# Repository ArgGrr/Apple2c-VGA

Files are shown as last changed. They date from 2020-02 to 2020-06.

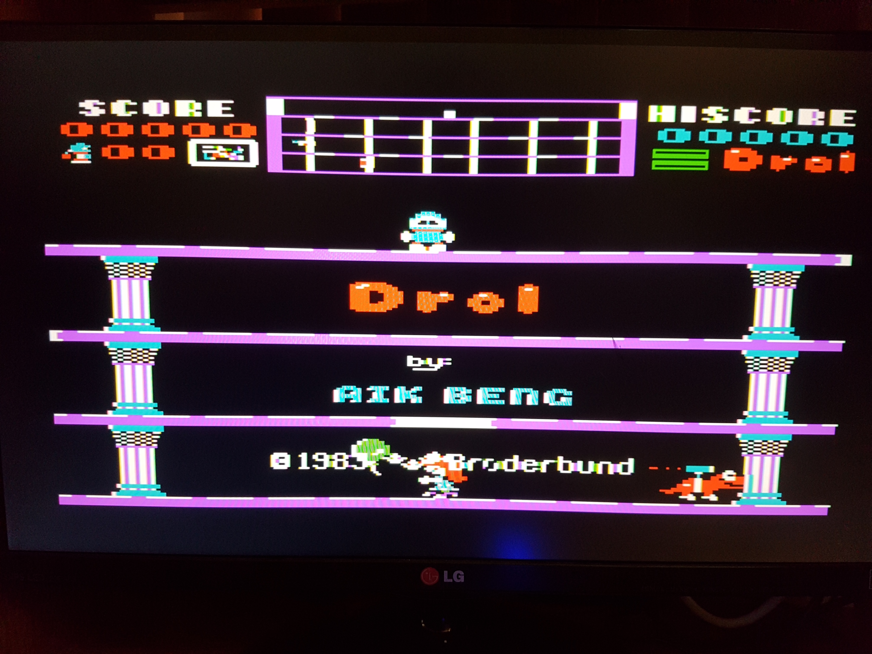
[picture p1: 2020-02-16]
Screenshots/DROL.jpg

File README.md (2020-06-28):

# Apple2cVGA

I have a PAL Apple 2c which does not produce colour on the composite output.
I made this project to learn about FPGAs and generate a nice VGA image from the Apple 2c video expansion port.

Supports:
- 40 & 80 column text in white. This includes the text in mixed graphics + text modes.
- GR & DGR colours
- HGR colours
- DHGR colours, including AppleWin-like sub-pixel rendering.

It is probably just easier to say it supports pixel accurate video output, but where text mode is drawn monochrome by default.

Various rendering modes, including:

0.  Monochrome (white)
1.  Monochrome (green)
2.  CREF mode
3.  140x192 resolution
4.  580x192 16 Colours no white text
5.  580x192 16 Colours, white text in tex/mixed mode. Default.
6.  Test pattern
7.  Monitor alignment pattern

Brief outline of how it works:
1. Track the A2 blanking signal, detect the horizontal and vertical blanking pulses, use in conjunction with 14MHZ clock to figure out horizontal pixel and vertical line counters.
2. Store the SERDATA bits in groups of 4, aligned to the CREF cycle, into the block RAM. Additionally, store the value of !GR at the start of each line, to determine if the line is TEXT or graphics mode.
3. Generate in a VGA sync module running from the VGA clock, horizontal pixel and vertical line counters.
4. Draw the data from the block RAM, depending on the rendering mode selected. Renders a 580 x 382 image, whith some padding before and after each line, and doubling the lines, onto a 640x480 VGA screen.

Verilog project done in [IceStudio](https://icestudio.io/).

Parts required:
- TinyFPGA BX
- 5v to 3v3  4 channel logic line level converter
- 12v to 5v regulator
- VGA pixel clock resonator, 25Mhz or there abouts. Better if it runs from 3.3v, otherwise you will need to route it through logic level converter.
- Bunch of resistors for the colour "DAC"
- Push button to change rendering mode

My design draws less than 30mA from the 12v line from the expansion port.

Points of interest:
- The NTSC Colourburst is aligned to the blanking output from the machine. Even though HGR and DHGR lines start at different times due to the different pixel clocks, if you count from the unblanking, you can infer the pixel colour later on. Therefore we don't need to store any CREF information in the block RAM.
- CREF rendering mode demonstrates this. Squint at it and the colours sort of match.
- By drawing DHGR 560x192 correctly, you get GR and HGR rendering for free.
- The sub pixel rendering mode is very close if not 100% the same as the Apple2 Win emulator, but I have no hardware (RGB Monitor etc) to reference it against.
- Because the Apple 2 TEXT or GRAPHICS mode is stored per line, things like Crazy Cycles 2c do not look exactly the same as a real machine. I.e. if it is drawing a small TEXT section at the start of a line, the whole line will be drawn black & white. This is an extreme case and I can live with it.
- The 140x192 rendering mode is bugged, the edges of the frame bleed out to the edges of the screen.
- 80col text is only really readable when rendered white / monochrome because of the sub pixel rendering mode, no doubt the same situations occur with a monitor.

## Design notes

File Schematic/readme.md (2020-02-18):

LibrePCB Schematic project. Work in progress.

Ports have swapped while I figure out the best layout.

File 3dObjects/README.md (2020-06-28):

OpenSCAD case to house the PCB in. For V1 PCB at this stage, will be redesigned to be smaller when V2 done.

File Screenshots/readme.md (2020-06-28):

Added some videos I took with my phone, I don't have a VGA capture card.
Note some of the Total Replay screens are demos are clamped in green & purple. I think this is a bug running it on the 2c.

Additionally, the Crazy Cycles demo shows the way the FPGA handles TEXT and graphics mode. What ever is set at the start of the line is maintained through the whole line. Not enough BRAM to store it for evey pixel.

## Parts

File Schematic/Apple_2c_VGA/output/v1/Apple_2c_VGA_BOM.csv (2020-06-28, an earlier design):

Quantity | Designators | Value | Device | Package
1 | CJ1 | CJMCU | CJMCU | CJMCU
1 | EXP1 | A2_exp_port | A2_exp_port | DB15_2ROW
1 | FPGA1 | TinyFPGA BX | TinyFPGA BX | TinyFPGA BX
1 | J1 | Vga | Vga | DHR-H15SR-D
1 | R1 | 10K | Resistor 2012 (0805) | RESC2012 (0805)
3 | R2, R5, R8 | 2,200Ω | Resistor 2012 (0805) | RESC2012 (0805)
3 | R3, R6, R9 | 1,500Ω | Resistor 2012 (0805) | RESC2012 (0805)
3 | R4, R7, R10 | 560Ω | Resistor 2012 (0805) | RESC2012 (0805)
1 | R11 | 1K | Resistor 2012 (0805) | RESC2012 (0805)
1 | S1 | Video Mode | button | Button
1 | S2 | RESET
1 | U2 | Reg | Reg | Reg

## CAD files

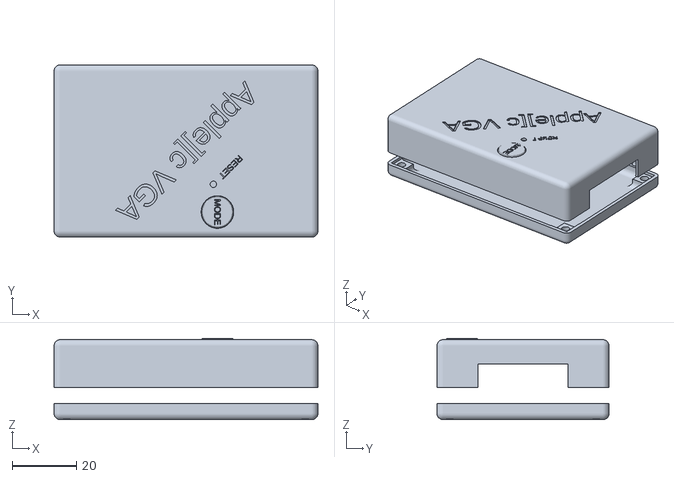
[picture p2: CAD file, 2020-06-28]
3dObjects/case.stl
82.4 x 53.8 x 25.4

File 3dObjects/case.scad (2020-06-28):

include <core.scad>
use <utils/layout.scad>
include <vitamins/buttons.scad>
include <vitamins/d_connectors.scad>
include <../../common.scad>

$fn= $preview ? 8 : 30;

//Global vars
wall=1;     //Default wall thickness
grid=2.54;  //Grid size..
tol=0.1;    //Size of gap between mating surfaces, account for printing

//Board Vars
board_width=79.43;
board_depth=50.8;
board_thick=1.2;

//Mode button location
button_x=49.53;
button_y=6.35;

//Reset hole location
reset_x=48.26;
reset_y=15;


//Case vars
case_width=board_width+3;
case_bottom_height=5;
case_top_height = 17;
case_depth=board_depth+3;
case_round=2;
corner_block=6;

case_top_elevate=10;

cap_height=4;
cap_rad=5;


//Drill holes for screws in corners
// could make the corner blocks related to this size and move the drill holes etc
screw_r1=1.5;
screw_h1=10;
screw_r2=3;
screw_h2=2;





if ($preview)
{


    //Button extension
    translate([board_width/-2,board_depth/-2,case_top_elevate-1])
        translate([button_x,button_y,10-tol])
        cap();
        
    //Case top
    case_top();

    //Case bottom
    color("lightgreen")
        case_bottom();
        
    //Board
    //translate([board_width/-2,board_depth/-2,4.1])
    //    Apple2cVGA();
}
else
{
    //Button extension
    translate([0,120,-21.4])
        translate([board_width/-2,board_depth/-2,case_top_elevate-1])
        translate([button_x,button_y,10-tol])
        cap();
    
    //Case top
    color("red")
    translate([0,60,24.915])
        rotate([0,180,0])
        case_top();


    //Case bottom
    translate([0,0,-0.085])
    color("lightgreen")
        case_bottom();
    
    
}




//
module button_cutout(tolerance=0)
{
    translate([button_x,button_y])
        cylinder(r=cap_rad+tolerance,h=case_top_height+1);
}
//
module cap(tolerance=0)
{
    //Not a replacement, should sit on top of button cap in a tube set into the lid.
    translate([0,0,0])

        difference()
        {
            color("yellow")
            minkowski()
            {
                translate([0,0,3])
                cylinder(r=cap_rad-0.5+tolerance,h=cap_height-0.5*2);
                sphere(r=0.5);
            }

                translate([0,0,cap_height-0.4+2.5])
                    rotate([0,0,270])
                    color("red")
                    linear_extrude(0.5)
                    text("MODE",size=2,halign="center",valign="center");

        }
        color("green")
            translate([0,0,2.5])
            cylinder(r=cap_rad+wall+tolerance,h=0.5);

}

//
module case_top()
{
 difference()
{
    union()
    {
        color("lightblue",0.3)
            translate([0,0,case_top_elevate])
            translate([0,0,-case_round])
            difference()
            {

                //Hollow out box
                difference()
                {
                    RoundedCube3D(case_width,case_depth,case_top_height,case_round);
                    //void            
                    translate([0,0,wall])
                    color("purple")
                    union()
                    {
                        //Stagger cutouts to create solid corners
                       RoundedCube3D(case_width-wall*2-corner_block*2,case_depth-wall*2,case_top_height-wall*2,case_round); 
                       RoundedCube3D(case_width-wall*2,case_depth-wall*2-corner_block*2,case_top_height-wall*2,case_round);
                    }

                        
                }
                
                //slice bottom off box
                translate([-case_width,-case_depth,-1])
                    color("red")
                    cube([case_width*2,case_depth*2,case_round+1]);
            }
 
        //tube for the mode button to float in
        color("purple",.4)
            translate([board_width/-2,board_depth/-2,case_top_elevate])
            translate([button_x,button_y,case_top_height-5])
            cylinder(r=cap_rad+wall,h=3);   
        
    }
    union()
    {
        //cut hole for reset button
        translate([board_width/-2,board_depth/-2,case_top_elevate-1])
            button_cutout(tol*2);   //interference fit on test print
        //Text
        translate([0,0,case_top_height+case_top_elevate-2-0.4])
            rotate([0,0,225])
            color("red")
            linear_extrude(2)
            text("Apple][c VGA",size=7,halign="center",valign="center");
        translate([14,-5,case_top_height+case_top_elevate-2-0.4])
            rotate([0,0,225])
            color("red")
            linear_extrude(2)
            text("RESET",size=2,halign="center",valign="center");
        //cut plug holes
        translate([board_width/-2,board_depth/-2,4.1])
            Apple2cVGA();
        //Drill screw holes
        translate([board_width/-2,board_depth/-2,case_top_elevate])
            board_drill(h1=case_top_height-2);
    }
}
}
//
module case_bottom()
{
    //Slice top off
    difference()
    {

        //Hollow out box
        difference()
        {
            RoundedCube3D(case_width,case_depth,case_bottom_height+case_round,case_round);
            
            translate([0,0,wall])
            color("purple")
            union()
            {
                //Stagger cutouts to create solid corners
               RoundedCube3D(case_width-wall*2-corner_block*2,case_depth-wall*2,case_bottom_height+case_round-wall*2,case_round); 
               RoundedCube3D(case_width-wall*2,case_depth-wall*2-corner_block*2,case_bottom_height+case_round-wall*2,case_round);
                
                //Route out the board shape to give it a pit to sit in.
                translate([0,0,9-board_thick])
                cube([board_width+tol*2,board_depth+tol*2,10],true);
                
                //Drill out the screw drill holes into the base
                translate([board_width/-2,board_depth/-2,3.5])
                    board_drill();
                

            }

                
        }
        

        translate([-case_width,-case_depth,case_bottom_height])
            color("red")
            cube([case_width*2,case_depth*2,case_bottom_height+case_round+1]);
    }



}
//
module Apple2cVGA()
{
    
    //board
    difference()
    {
        color("darkgreen")
            cube([board_width,board_depth,1]);
        //Drill holes
        board_drill();
    }
        
    //regulator
    color("orange")
        translate([25.4,25.4,5.5])
            cube([21,44,10],true);
    
    //TinyFPGA BX
    color("lightblue")
        translate([48.26,30.48,2.5])
            cube([18.5,35.6,4],true);    

    //cutout for USB plug
    color("red")
        translate([48.26,50,2.5])
            RoundedCube3D(11,11,7,.5);    
    
    //cutout for reset button
    color("red")
        translate([reset_x,reset_y,2.5])
            cylinder(r=1,h=20);

    //Button
    translate([button_x,button_y,0])
        mode_button();
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

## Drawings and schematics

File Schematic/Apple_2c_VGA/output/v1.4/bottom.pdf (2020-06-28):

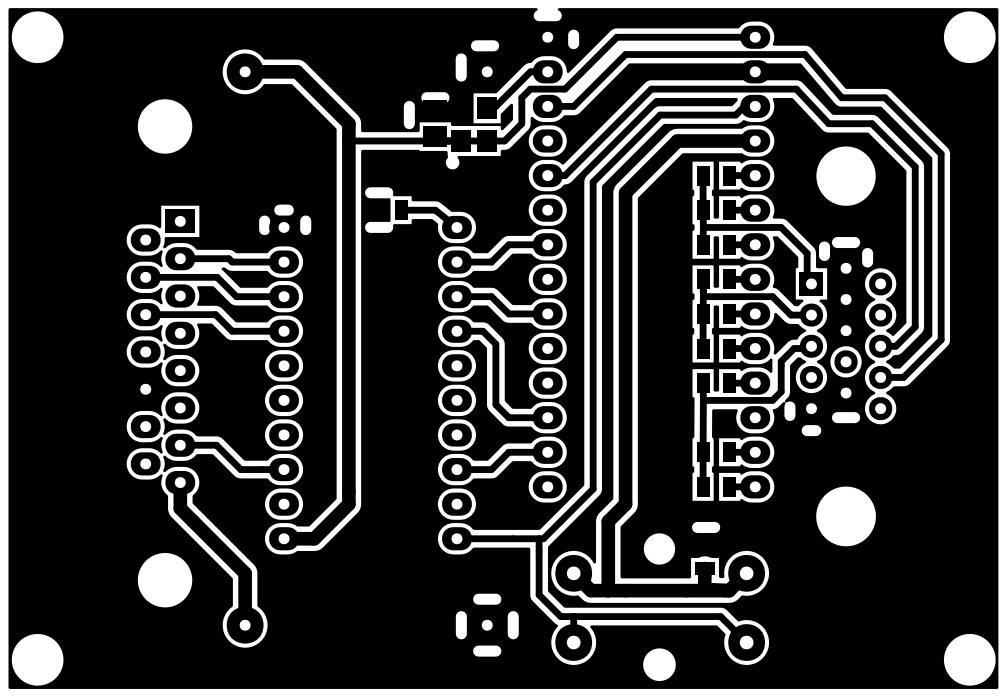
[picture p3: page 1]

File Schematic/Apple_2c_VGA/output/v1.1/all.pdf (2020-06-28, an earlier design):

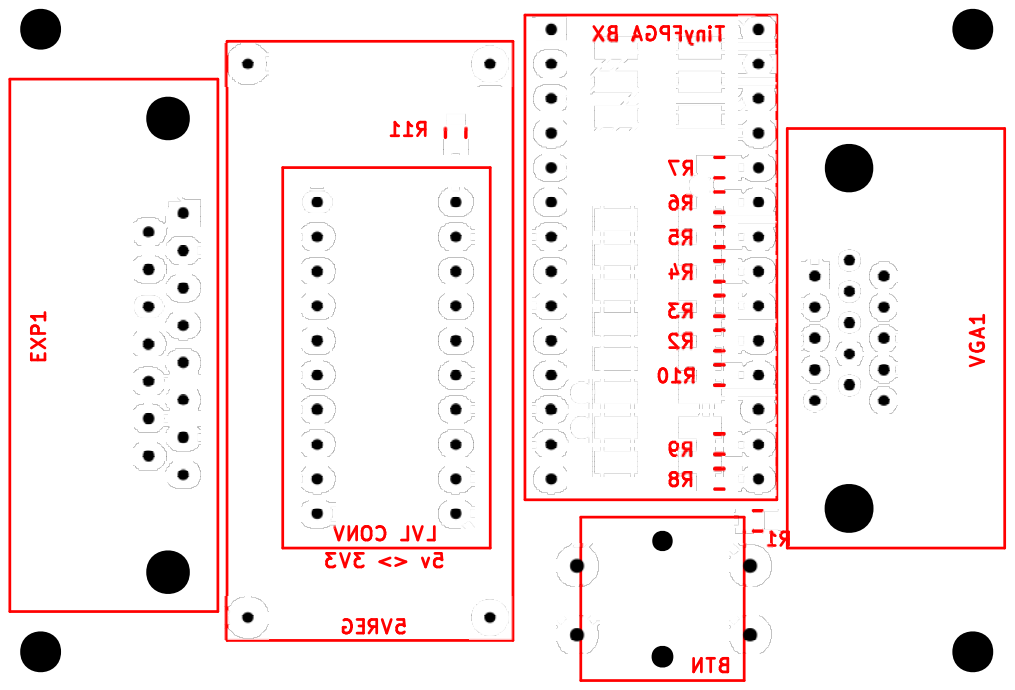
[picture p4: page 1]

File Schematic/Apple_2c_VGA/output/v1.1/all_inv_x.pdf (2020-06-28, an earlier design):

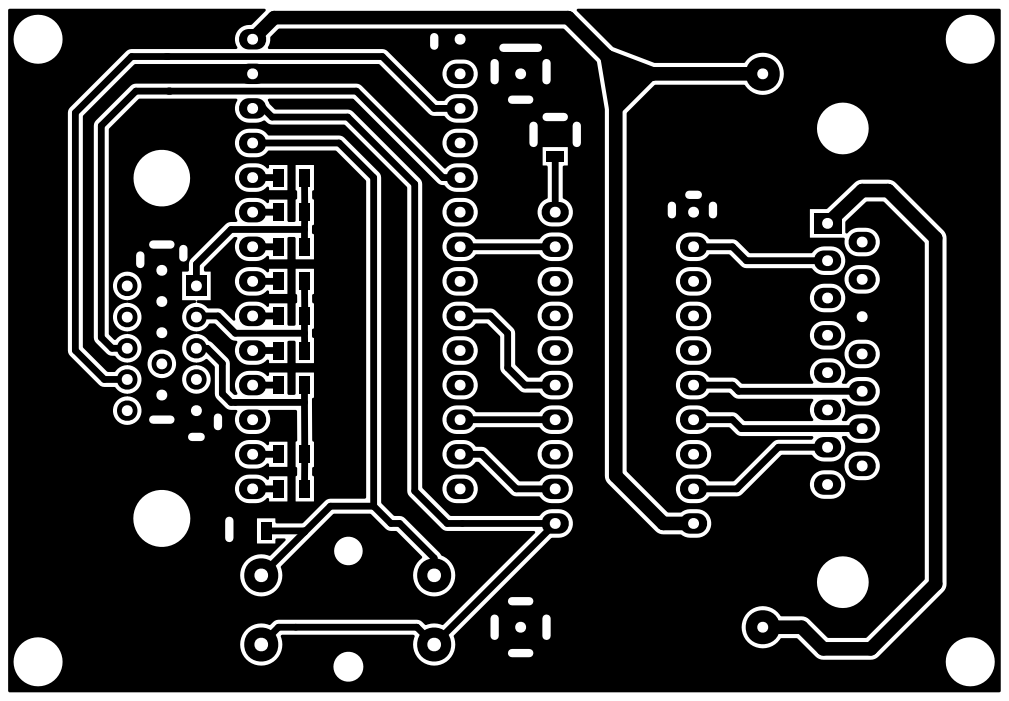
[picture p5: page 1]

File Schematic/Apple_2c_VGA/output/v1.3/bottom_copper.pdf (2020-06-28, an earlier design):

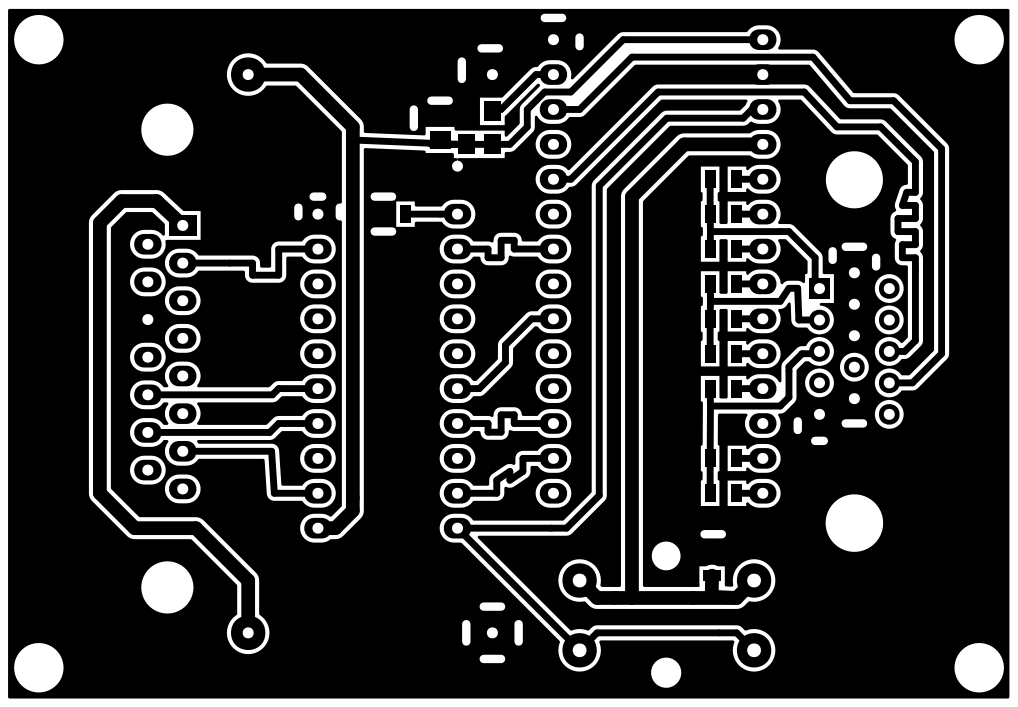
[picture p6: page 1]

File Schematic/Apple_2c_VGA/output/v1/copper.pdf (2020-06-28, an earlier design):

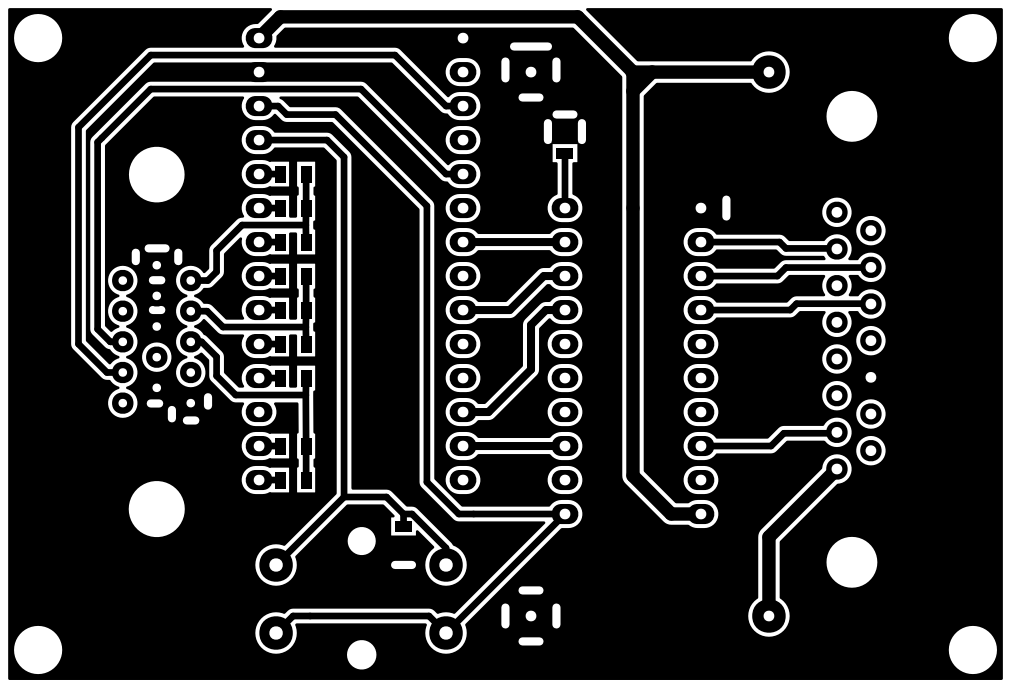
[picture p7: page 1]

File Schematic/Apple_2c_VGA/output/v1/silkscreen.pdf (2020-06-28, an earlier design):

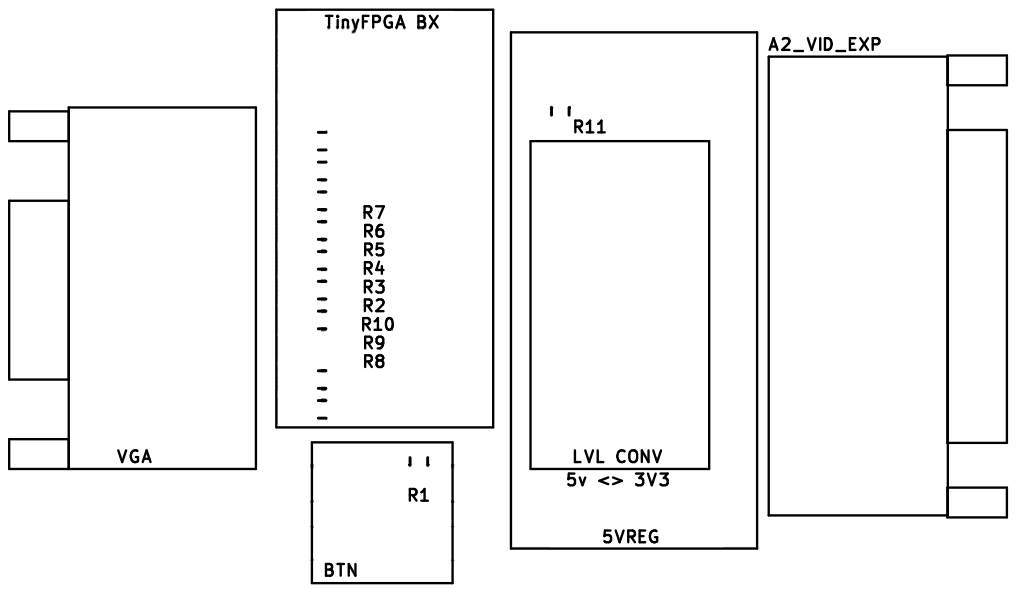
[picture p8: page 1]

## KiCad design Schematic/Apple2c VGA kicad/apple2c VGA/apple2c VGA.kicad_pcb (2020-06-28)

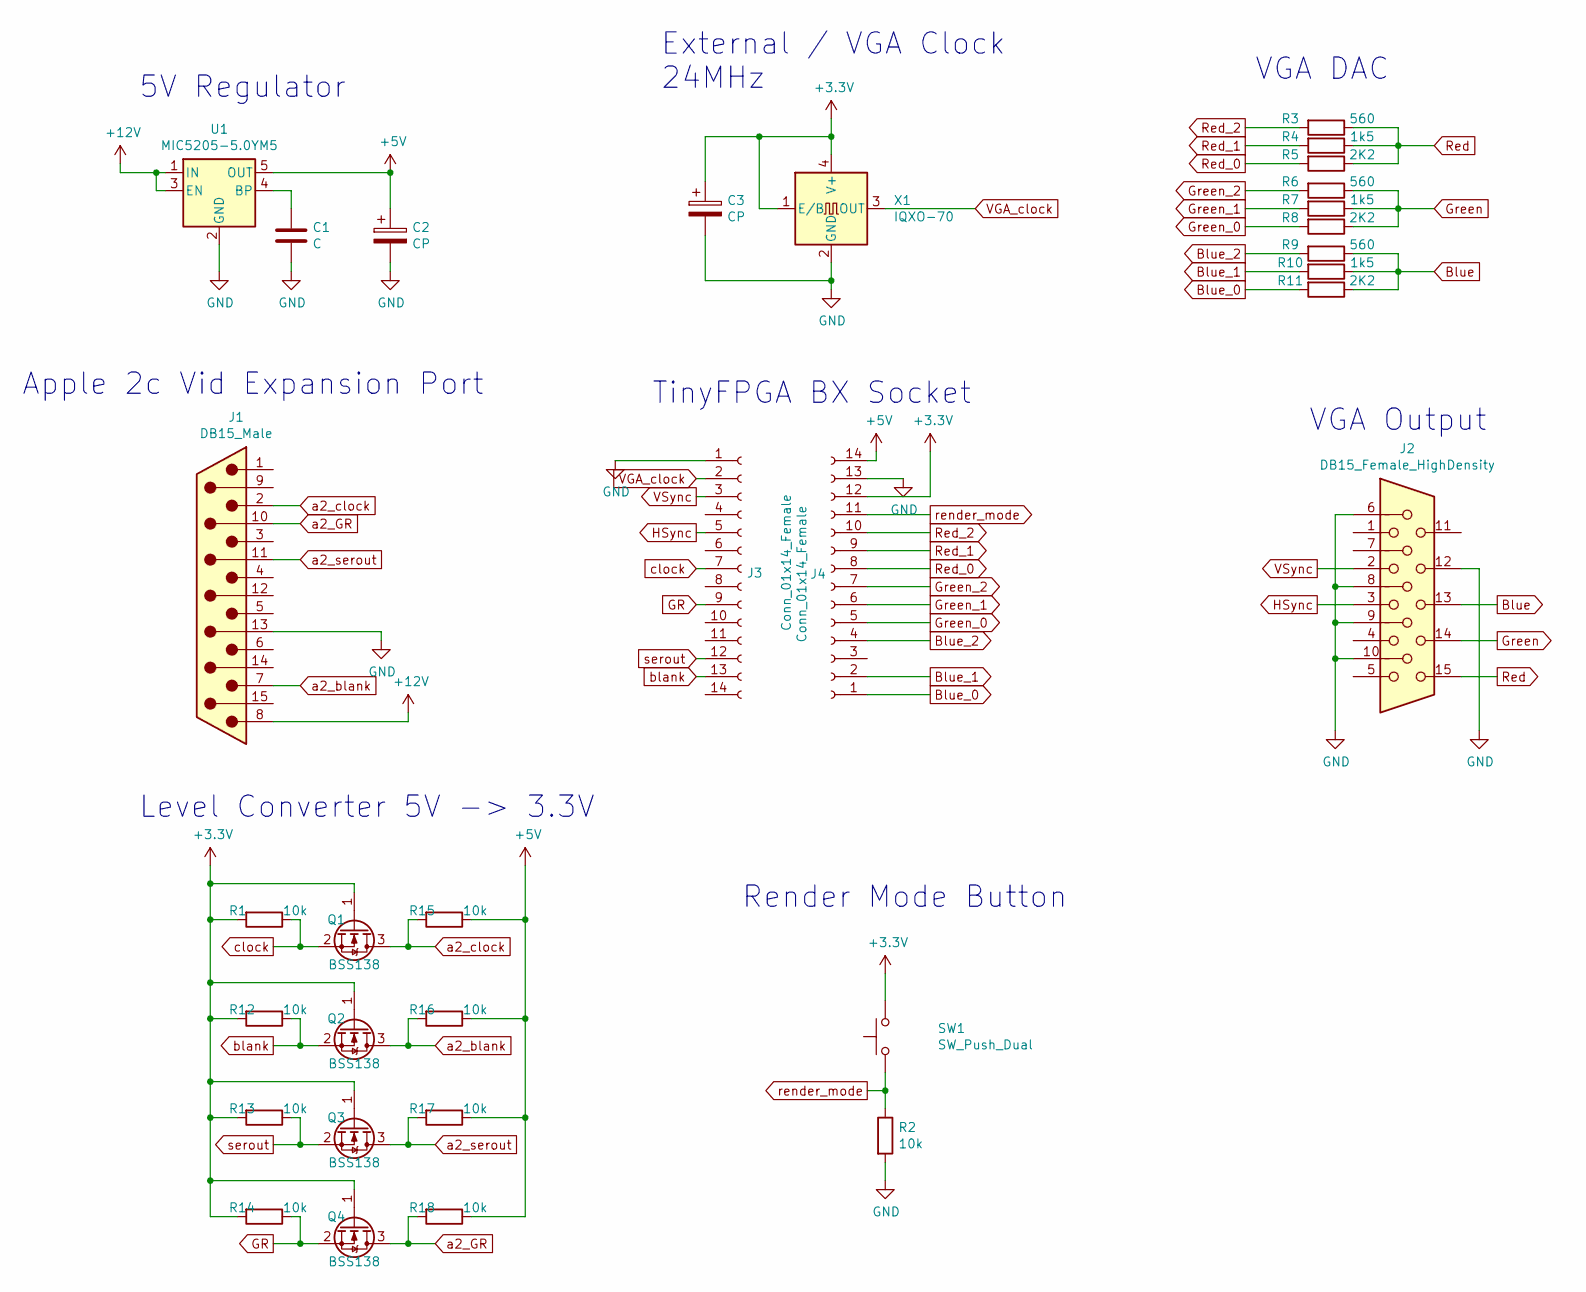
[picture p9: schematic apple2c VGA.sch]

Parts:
C1: C; C_0805_2012Metric
C2, C3: CP; C_0805_2012Metric
J1: DB15_Male; DSUB-15_Male_Horizontal_P2.77x2.84mm_EdgePinOffset4.94mm_Ho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
J2: DB15_Female_HighDensity; DSUB-15-HD_Female_Horizontal_P2.29x1.98mm_EdgePinOffset3.03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
J3, J4: Conn_01x14_Female; PinSocket_1x14_P2.54mm_Vertical
Q1, Q2, Q3, Q4: BSS138; SOT-23
R1, R2, R12, R13, R14, R15, R16, R17, R18: 10k; R_0805_2012Metric
R3, R6, R9: 560; R_0805_2012Metric
R4, R7, R10: 1k5; R_0805_2012Metric
R5, R8, R11: 2K2; R_0805_2012Metric
SW1: SW_Push_Dual; SW_PUSH-12mm
U1: MIC5205-5.0YM5; SOT-23-5_HandSoldering
X1: IQXO-70; Oscillator_SMD_IQD_IQXO70-4Pin_7.5x5.0mm

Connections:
+3V3: C3.1, J4.12, Q1.1 (G), Q2.1 (G), Q3.1 (G), Q4.1 (G), R1.2, R12.2, R13.2, R14.2, SW1.2, X1.1 (E/B), X1.4 (V+)
+5V: C2.1, J4.14, R15.1, R16.1, R17.1, R18.1, U1.5 (OUT)
+12V: J1.8, U1.1 (IN), U1.3 (EN)
Blue: J2.13, R9.1, R10.1, R11.1
Blue_0: J4.1, R11.2
Blue_1: J4.2, R10.2
Blue_2: J4.4, R9.2
GND: C1.2, C2.2, C3.2, J1.13, J2.6, J2.8, J2.9, J2.10, J2.12, J3.1, J4.13, R2.2, U1.2 (GND), X1.2 (GND)
GR: J3.9, Q4.2 (S), R14.1
Green: J2.14, R6.1, R7.1, R8.1
Green_0: J4.5, R8.2
Green_1: J4.6, R7.2
Green_2: J4.7, R6.2
HSync: J2.3, J3.5
unnamed: C1.1, U1.4 (BP)
Red: J2.15, R3.1, R4.1, R5.1
Red_0: J4.8, R5.2
Red_1: J4.9, R4.2
Red_2: J4.10, R3.2
VGA_clock: J3.2, X1.3 (OUT)
VSync: J2.2, J3.3
a2_GR: J1.10, Q4.3 (D), R18.2
a2_blank: J1.7, Q2.3 (D), R16.2
a2_clock: J1.2, Q1.3 (D), R15.2
a2_serout: J1.11 (P111), Q3.3 (D), R17.2
blank: J3.13, Q2.2 (S), R12.1
clock: J3.7, Q1.2 (S), R1.1
render_mode: J4.11, R2.1, SW1.1
serout: J3.12, Q3.2 (S), R13.1

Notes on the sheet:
Level Converter 5V -> 3.3V
Render Mode Button
5V Regulator
External / VGA Clock 24MHz
VGA DAC
VGA Output
TinyFPGA BX Socket
Apple 2c Vid Expansion Port

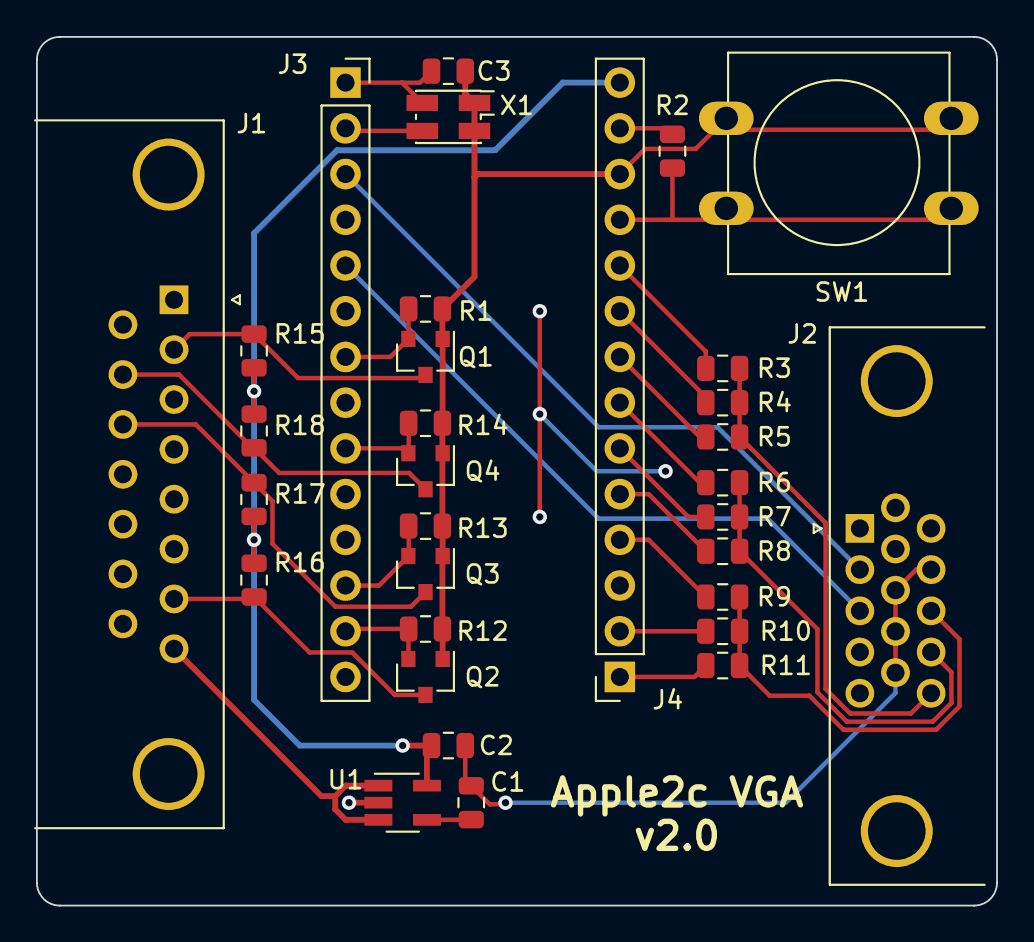
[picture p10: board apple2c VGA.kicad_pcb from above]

Board: 2 copper layers, 53.3 x 48.3 mm, 32 parts (0 on the bottom side), 29 nets.

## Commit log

2020-02-16 v1
    Initial dump of v1 files.
    [CVTv1r1_2.xls, DHGR investigation.ods, pll1.ods]
2020-02-16 Schematic Libraries
2020-02-18 Add 3d models
    [db-19.scad, db-19.stl]
2020-02-23 Schematic, 3d model updates
    Semi-finalised the schematic. Pending parts on order and attempted build.
    Working on 3d model for DB19 plug for disk drive port, sd card project.
    [Apple_2c_VGA_COPPER-BOTTOM.gbr, Apple_2c_VGA_COPPER-TOP.gbr, Apple_2c_VGA_DRILLS-NPTH.drl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]
2020-02-24 Case
    Started building a case, pending first build of the board of course.
    [case.scad]
2020-02-26 Adding standalone reset button cap
    [case.scad]
2020-02-28 Updated mode button.
    [case.scad]
2020-03-02 working on case
    [case.scad, case.stl]
2020-03-04 Working on case for smartport sd device
    [unidisk_case.scad]
2020-03-09 Various updates
    [joystick.brd, joystick.sch, light_tube.stl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]
2020-06-28 First PCB and build done, reworking.
    Built first version, had some issues. Reworking the PCB design in KiCAD. FPGA tweaked slightly to fix a colour bug and to remap IO.
    [Apple_2c_VGA_BOM.csv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]
2020-06-28 Tidy up
    [apple2c VGA.kicad_pcb]
